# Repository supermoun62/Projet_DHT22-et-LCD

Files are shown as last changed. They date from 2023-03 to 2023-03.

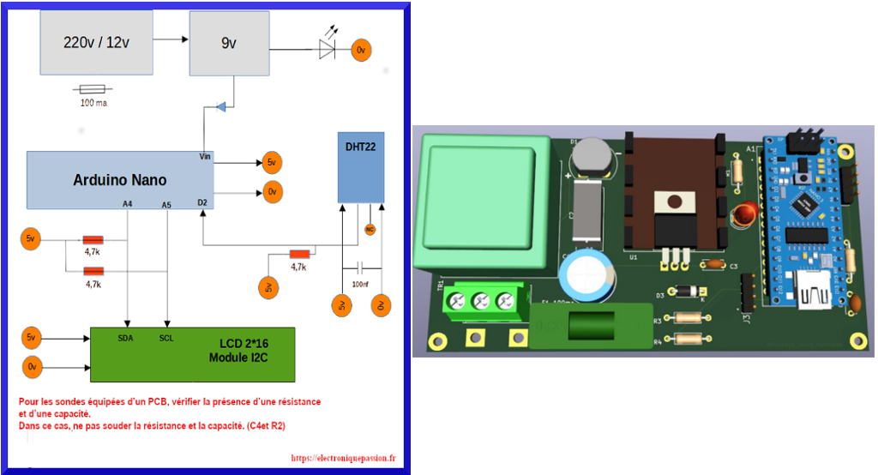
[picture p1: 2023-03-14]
Image_Synoptique_et_PCB_Affichage_DHT22.png

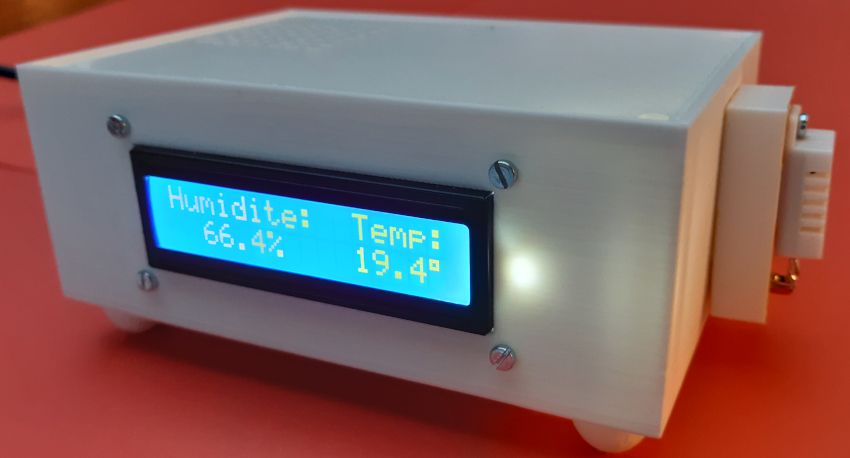
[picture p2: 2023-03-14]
Image_Coffret_Fini_V2.png

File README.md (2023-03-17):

# Projet_DHT22-et-LCD
Programme pour afficher H et T directement de la sonde: Affichage_DHT22_H_et_T.ino

Programme pour afficher H et T sur le LCD: Programme pour afficher H et T.ino.

Librairies: Adafruit_Sensor-master.zip  DHT-sensor-library-master.zip  LiquidCrystalI2C112.zip

Calibration_Affichage_DHT22: DHT22_Calibration_Temperature.pdf

Documentations techniques

Image 3D du PCB: DHT22_Calibration_Temperature.jpg.

Liste du materiel:  Liste_Materiel_Affichage_Temp_Humidite.pdf.

PCB Gerber.

PCB Pdf.

Schema: Affichage_Temp_Humidite.pdf.

Fichiers STL.

Le detail du projet:  Arduino_Affichage_DHT22.pdf.

https://github.com/supermoun62/Projet_DHT22-et-LCD/blob/main/Image_Coffret_Fini_V2.png

https://github.com/supermoun62/Projet_DHT22-et-LCD/blob/main/Image_Synoptique_et_PCB_Affichage_DHT22.png

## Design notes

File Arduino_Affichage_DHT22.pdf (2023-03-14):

## Arduino – Affichage température et Humidité avec un DHT22

Affichage température et Humidité avec un DHT22 | http://electroniquepassion.fr

### 1 Sur 10

# PROJET

Afficher la température et l’humidité avec in DHT22 et un écran LCD 12*16 avec un bus I2C

220v / 12v | 9v

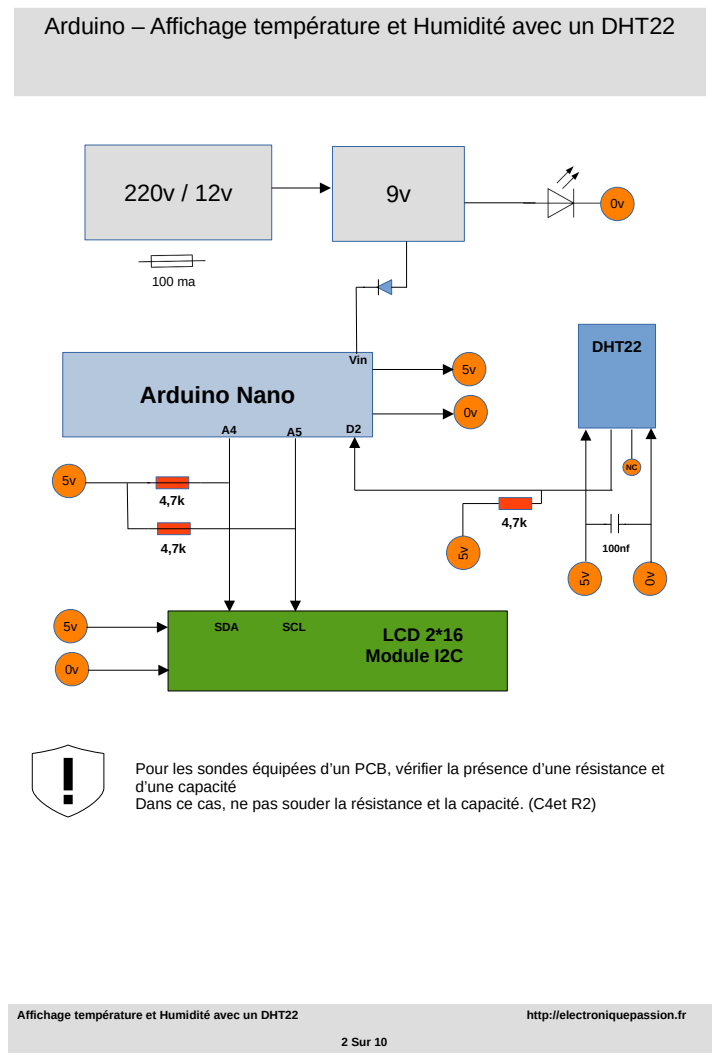
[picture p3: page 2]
2 Sur 10; Arduino Nano; LCD 2*16 Module I2C; SDA; SCL; DHT22; Vin

Pour les sondes équipées d’un PCB, vérifier la présence d’une résistance et
d’une capacité
Dans ce cas, ne pas souder la résistance et la capacité. (C4et R2)

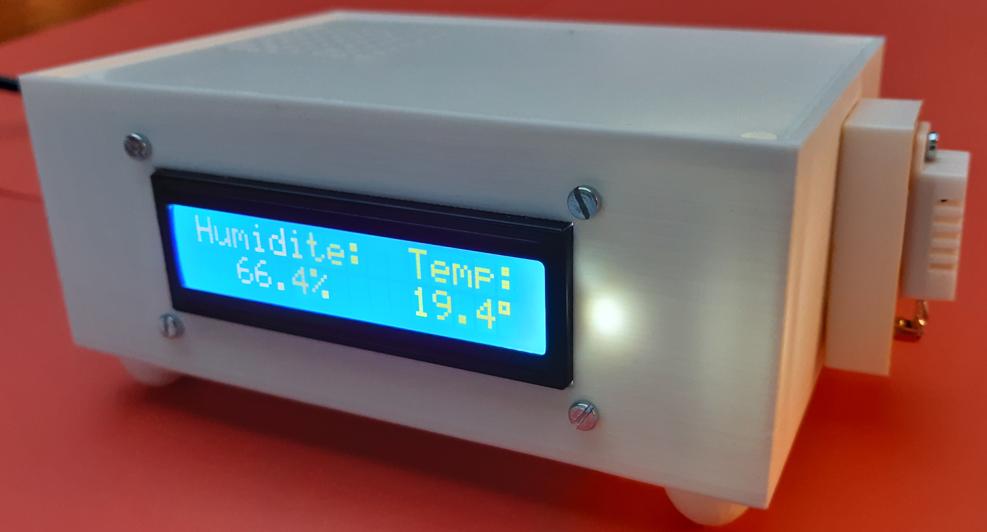
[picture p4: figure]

### 3 Sur 10

Matériel utilisé:

Arduino Nano

LCD 2*16 Bus I2C
DHT22

Librairies:
Wire.h
LiquidCrystal_I2C (https://github.com/sui77/rc-switch) | ICI (https://github.com/fdebrabander/Arduino-LiquidCrystal-I2C-library) ou par le gestionnaire de librairies ou (https://github.com/sui77/rc-switch) ICI (https://www.gotronic.fr/pj2-sbc-lcd16x2-fr-1441.pdf) DHT-sensor-library de Adafruit (https://github.com/sui77/rc-switch)

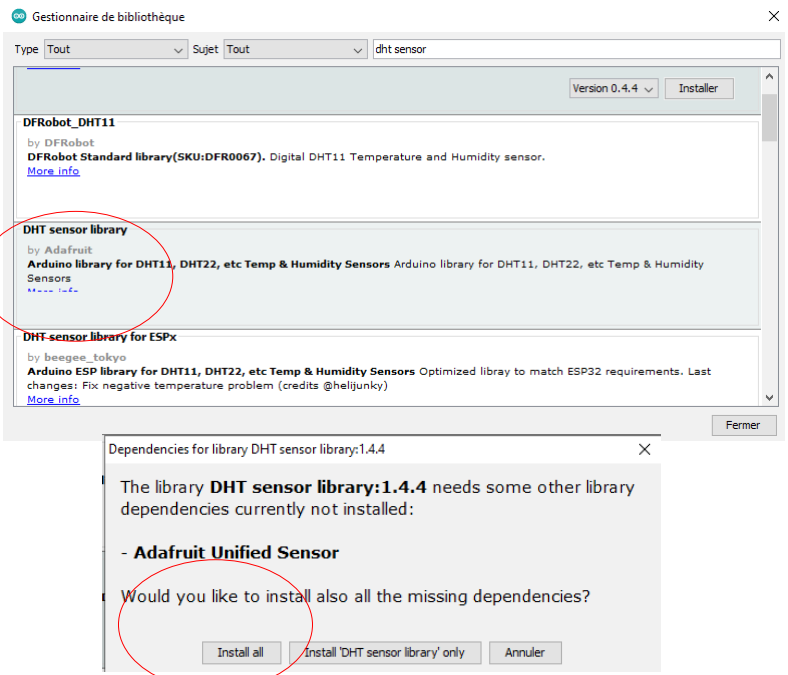
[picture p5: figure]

### 4 Sur 10

### 5 Sur 10

| DHT11 | DHT22 (2302)
U | 3 à 5,5v | 3,3 à 6v
Plage de mesures | 0°c à 50°c | -40°c à 80°c
Précision température | ± 2°c | ±- 0,5°c
Résolution température | 1°c | 0,1°c
Plage de mesures humidités | 20 % à 80 % | 0 % à 100 %
Précision humidité | ± 5 % | ± 2 à 5 %
Résolution humidité | 1 % | 0,1 %
Courant max | 2,5ma | 1,5ma
Courant au repos | 150µa | 50µa
Fréquence collecte mesures | 1 par seconde | 2 par seconde

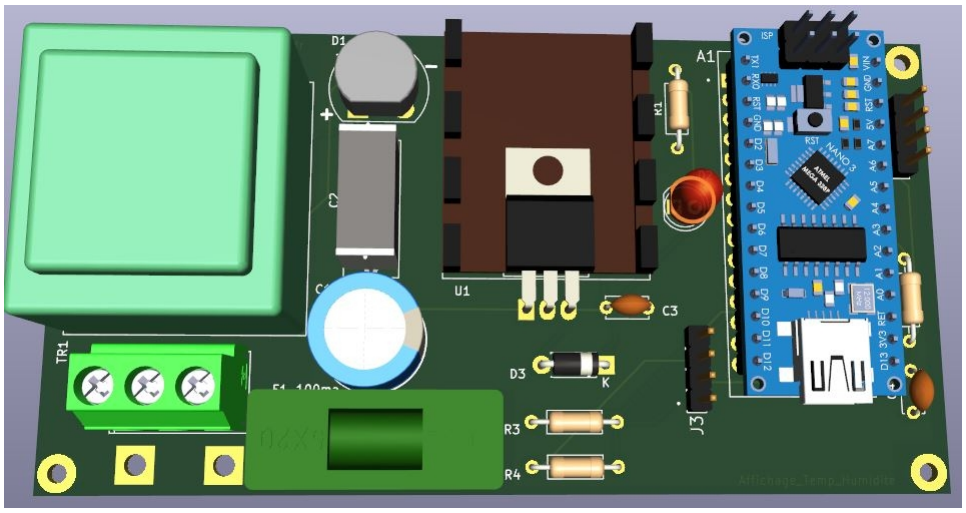
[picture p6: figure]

### 6 Sur 10

## PCB embase 15br

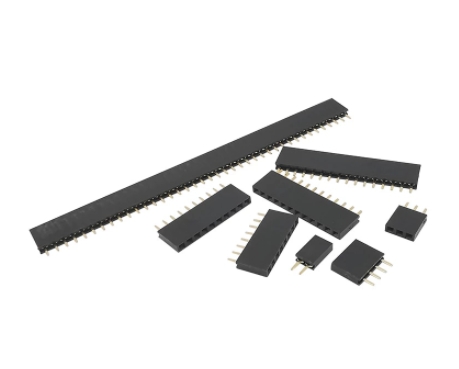
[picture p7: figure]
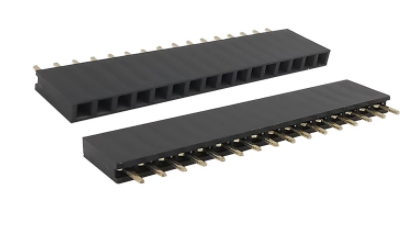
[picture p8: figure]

### 7 Sur 10

ICI (https://fr.aliexpress.com/item/4000852908837.html?spm=a2g0s.9042311.0.0.41a46c372WkNYm)

### 8 Sur 10

DHT | T Réelle | Corrigé
17,5 | 16 | 15,96
18,6 | 17 | 17,02
19,7 | 18 | 18,08
20,6 | 19 | 18,94
0 | 5 | 10 | 15 | 20 | 25

0

5

10

15

20

f(x) = 0,9594 Val_T − 0,8247 R² = 0,9978

Courbe de tendance avec couvercle

DHT22 valeur T

T

Réelle

J’ai repris le tuto de Steph Ubaud: https://www.youtube.com/watch?v=lJU6JCm94O8

Ou Tutoriel Calc - nuage de points et courbe d'ajustement (https://scolawebtv.crdp-versailles.fr/?id=36132) de Vincent Schoeffter

Pour les relevés de mesure , utiliser le fichier : Affichage_DHT22_H_et_T.ino

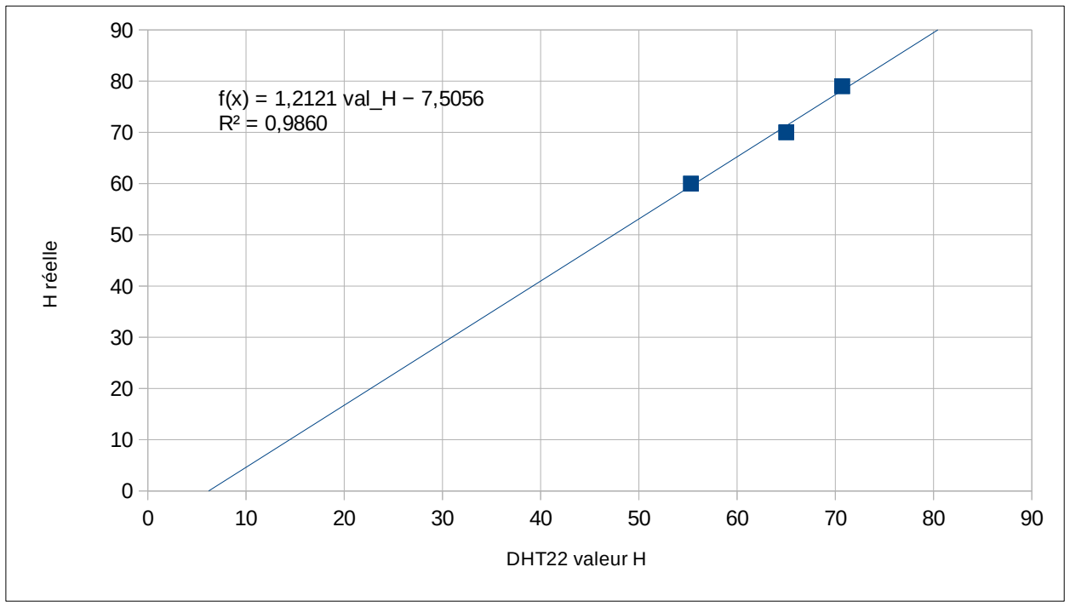
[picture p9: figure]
f(x) = 1,2121 val_H − 7,5056 R² = 0,9860; DHT22 valeur H; H réelle

### 9 Sur 10

DHT | H Réelle | Corrigée
49,6 | 54 | 52,61
55,3 | 60 | 59,52
65 | 70 | 71,28
70,7 | 79 | 78,19

### 10 Sur 10

1:
Pour les essais, utiliser le fichier Affichage_DHT22_H_et_T.ino Coffret fermé afin de relever les valeurs de H et T fournies parle DHT22.

2:
Après les relevés, faire les courbes de tendance afin de calibrer la sonde.

3:
Corriger les valeurs dans le fichier Affichage_DHT22_V6.ino

4:
Téléverser le programme Affichage_DHT22_V6.ino.

Ruban adhésif thermique
Cpix.fr réf : D00827-V3

## COFFRET

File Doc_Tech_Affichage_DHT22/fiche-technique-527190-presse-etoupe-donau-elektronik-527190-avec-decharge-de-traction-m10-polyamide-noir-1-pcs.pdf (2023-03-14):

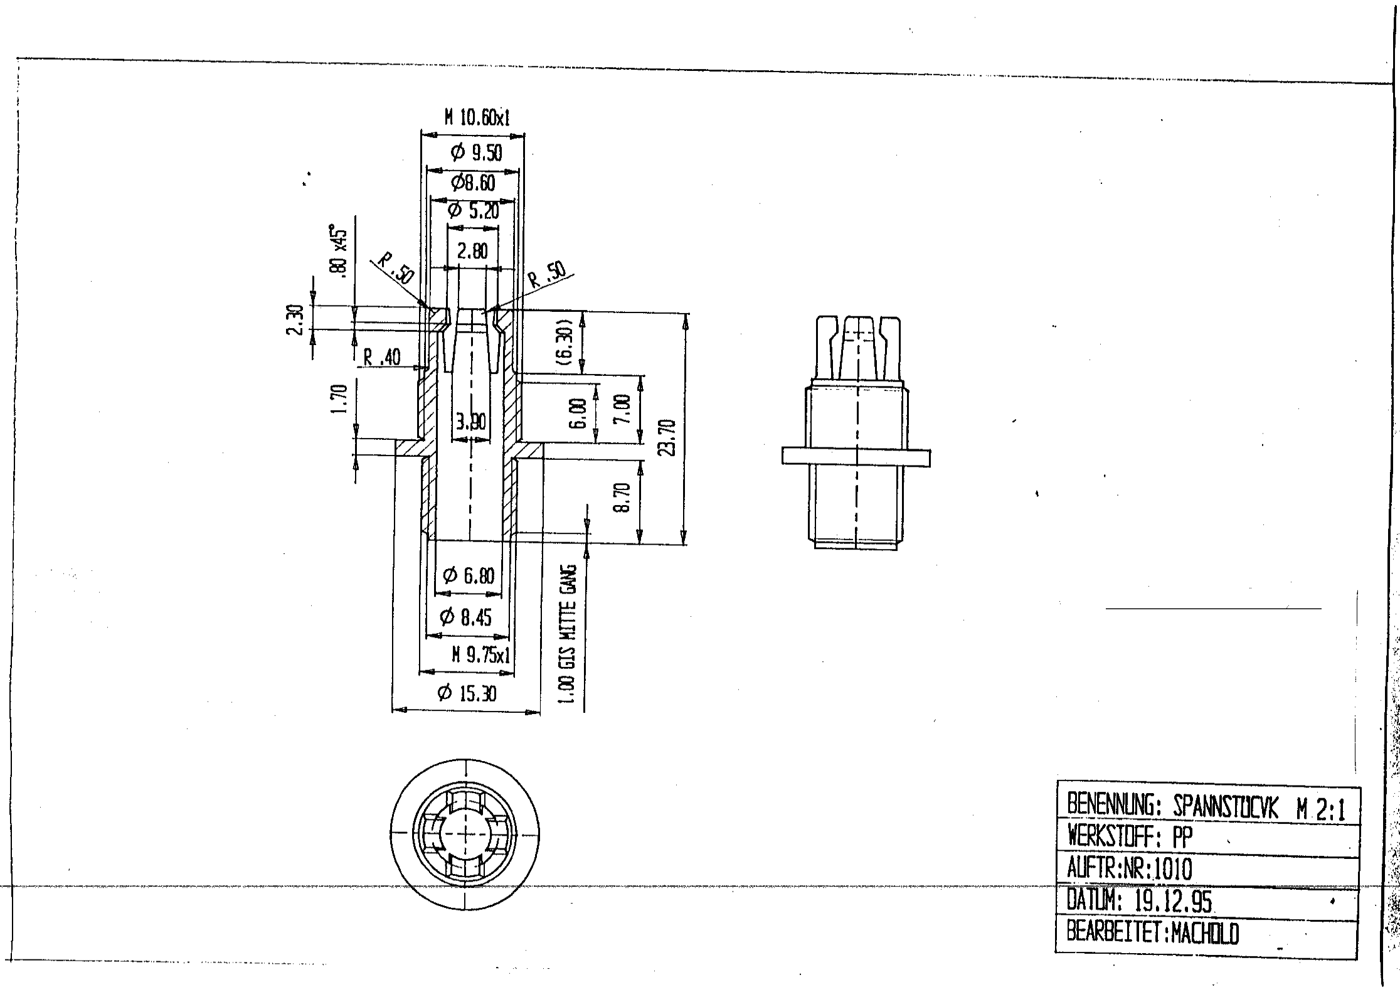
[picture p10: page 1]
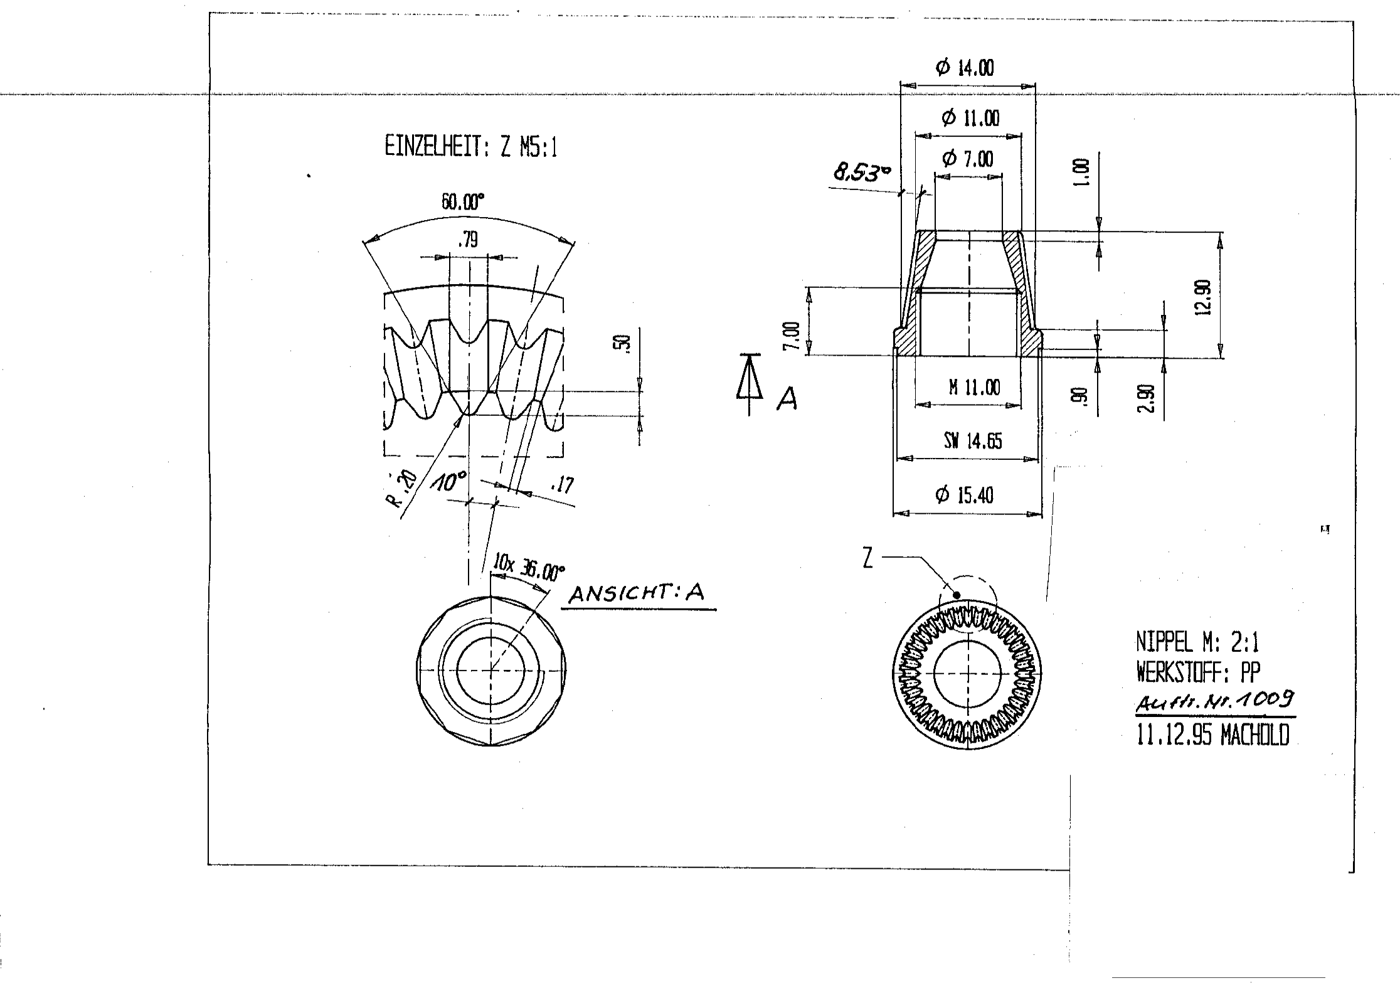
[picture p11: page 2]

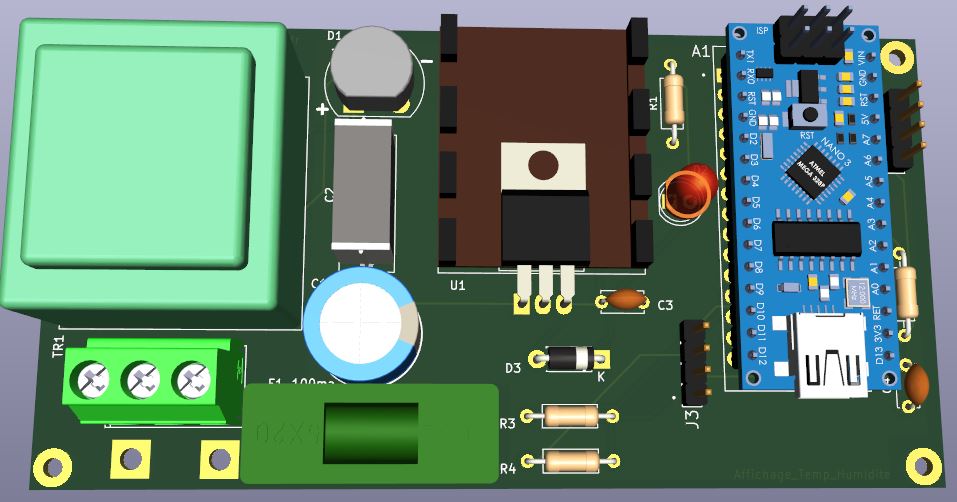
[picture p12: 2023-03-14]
Image_3D_Affichage_DHT22/Image-3D_V2_Affichage_Temp_Humidite.JPG

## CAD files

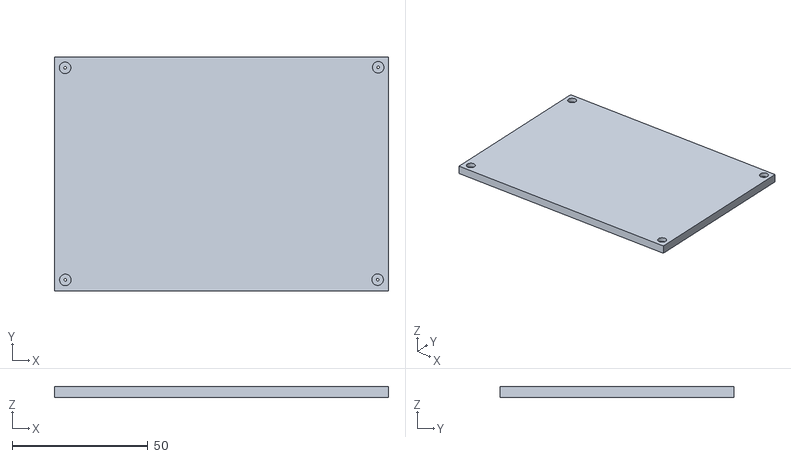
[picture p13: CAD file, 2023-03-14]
STL_Affichage_DHT22/Couvercle_Coffret_Affichage_DHT22_V2.stl
123.0 x 86.0 x 4.00

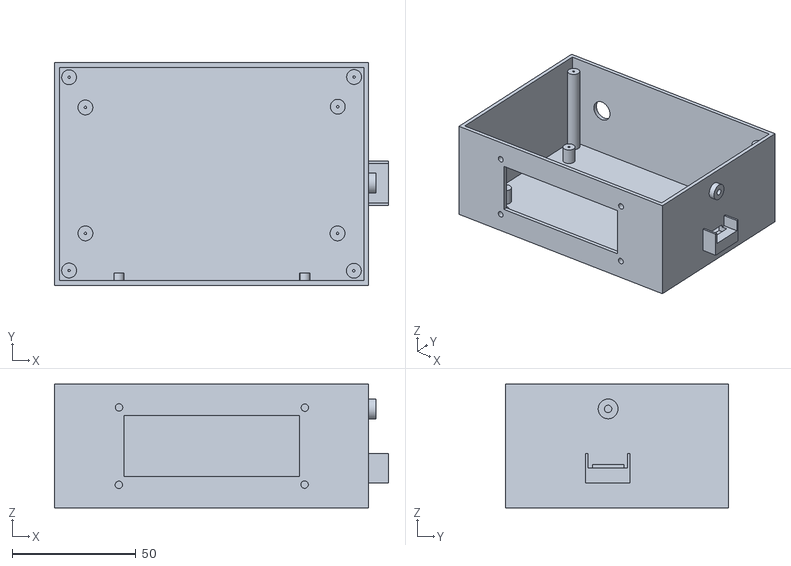
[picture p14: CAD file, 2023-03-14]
STL_Affichage_DHT22/Coffret_Affichage_DHT22_V3.stl
135.0 x 90.0 x 50.0

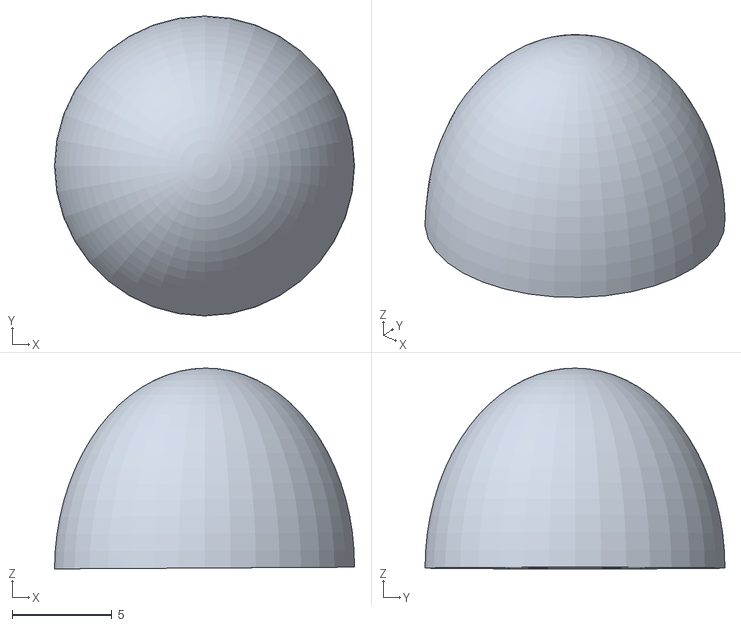
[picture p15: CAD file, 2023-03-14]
STL_Affichage_DHT22/Support_coffret_Affichage_DHT22.stl
15.0 x 15.0 x 10.0

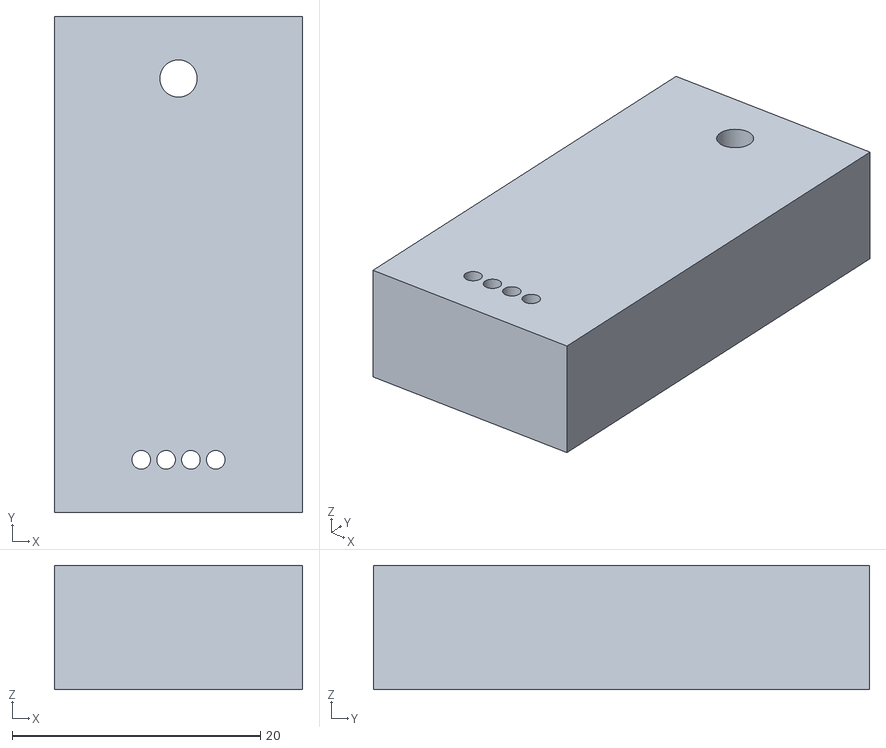
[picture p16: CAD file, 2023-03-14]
STL_Affichage_DHT22/Modification-DHT22.stl
20.0 x 40.0 x 10.0

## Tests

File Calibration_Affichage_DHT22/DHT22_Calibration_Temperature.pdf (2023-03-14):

DHT22_Calibration_Temperature, Page 1

DHT | T Réelle | Corrigée
17,5 | 16 | 15,96
18,6 | 17 | 17,02
19,7 | 18 | 18,08
20,6 | 19 | 18,94
0 | 5 | 10 | 15 | 20 | 25

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
f(x) = 0,9594 Val_T − 0,8247 R² = 0,9978

## Courbe de tendance avec couvercle

DHT22 valeur T

T

Réelle

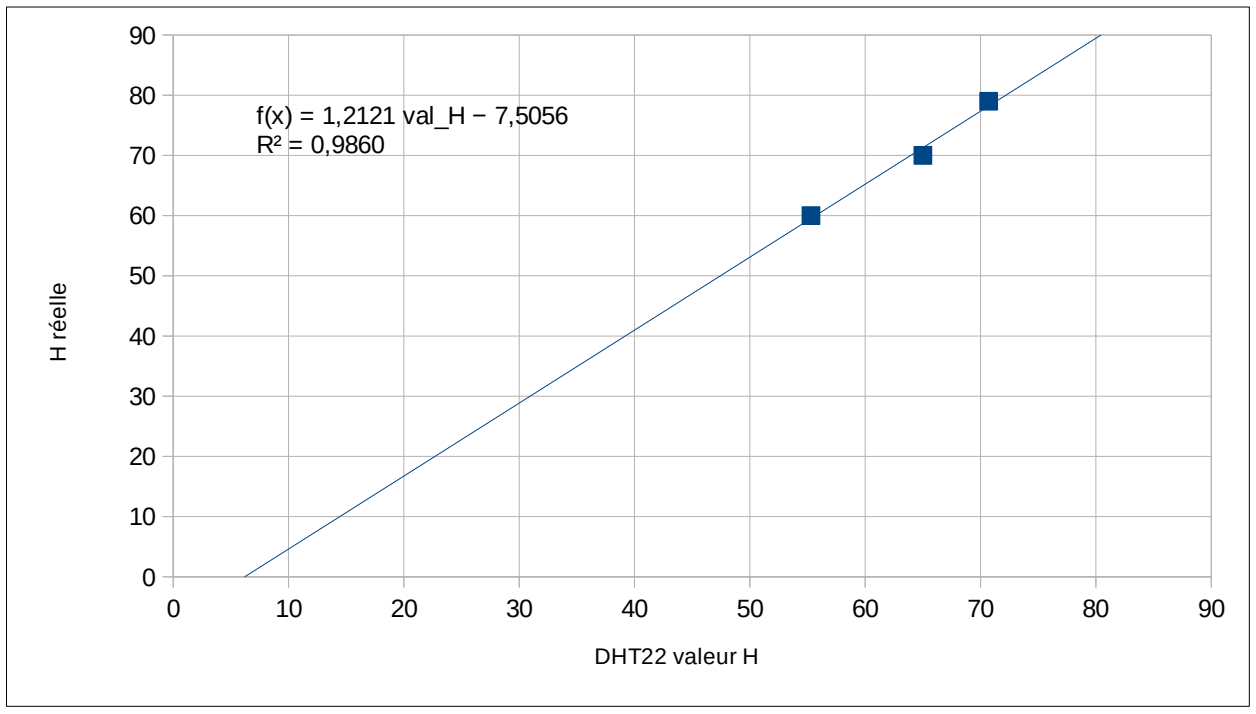
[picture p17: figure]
f(x) = 1,2121 val_H − 7,5056 R² = 0,9860; DHT22 valeur H; H réelle

DHT22_Calibration_Temperature, Page 2

DHT | H Réelle | Corrigée
49,6 | 54 | 52,61
55,3 | 60 | 59,52
65 | 70 | 71,28
70,7 | 79 | 78,19

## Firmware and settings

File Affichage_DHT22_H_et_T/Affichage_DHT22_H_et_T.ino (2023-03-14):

/*
 Description: Programme permettant d'afficher sur un afficheur liquid-crystal, température et taux d'humidité
              mesurés par un DHT22, branché sur la pin D2.

 Auteur:  Christian Mercier  
 Créé le:  

 Librairies utilisées: DHT sensor library https://github.com/adafruit/DHT-sensor-library
                                          https://github.com/adafruit/DHT-sensor-library                                        
                     : Liquid-crystal-I2C https://www.arduinolibraries.info/libraries/liquid-crystal-i2-c                                                                 
                     : Wire 
                     
 Informations sites:    https://www.volta.ma/comment-utiliser-les-capteurs-dht11-et-dht22-avec-arduino/arduino/
                        https://scolawebtv.crdp-versailles.fr/?id=36132  
                        https://www.youtube.com/watch?v=lJU6JCm94O8                                           
  */
#include <Wire.h>
#include <LiquidCrystal_I2C.h>
LiquidCrystal_I2C lcd(0x27,16,2);// Adresse,lignes,colonnes

#include <Adafruit_Sensor.h>
#include <DHT.h>
#include <DHT_U.h>

#define DHTPIN 2 // Pin raccordement DHT22
//#define DHTTYPE DHT11 // DHT 11
#define DHTTYPE DHT22 // DHT 22  (AM2302), AM2321
//#define DHTTYPE DHT21 // DHT 21 (AM2301)
DHT dht(DHTPIN, DHTTYPE); // Instance librairie DHT
  float valeurH = 0.0;
  float valeurT = 0.0;
  float valeurTcorrigee = 0.0;
  float valeurTressentie = 0.0;
  float valeurRessentieEnCelsius = 0.0;
  float var1T = 0.9594; // En fonction de la courbe de tendance
  float var2T = 0.8247; // En fonction de la courbe de tendance

  byte bitDefaut1;
  byte bitDefaut2;
  const int pinLed13 = 13;
//---------------------------------------
void setup ()
{     
  Serial.begin(9600);     
  dht.begin(); // Init DHT22;
  
  lcd.init();// init Afficheur                    
  lcd.backlight();// Active retro-eclairage
  lcd.setCursor(1,0);// Colonne, Ligne
  lcd.print(" Capteur DHT22");
      
  pinMode(pinLed13, OUTPUT);
  digitalWrite(pinLed13, LOW);     

  bitDefaut1 = LOW; 
  bitDefaut2 = LOW;
  
  delay(1000);  
  lcd.clear();// Effacement LCD     
}// fin Setup 
//--------------------------------------------
void loop ()
{
// Appel routine releves temp et humidité du DHT22
  InfosTempEtHumidite(); 
}// Fin LOOP
//--------------------------------------------
void InfosTempEtHumidite()
{  
  float H = dht.readHumidity(); // Humidité en %
  delay(100);
  float T = dht.readTemperature();
  delay(100);
  valeurRessentieEnCelsius = dht.computeHeatIndex(T, H, false); // False = °C
  valeurH = H;
  valeurT = T;
  valeurTressentie = valeurRessentieEnCelsius;
// Calcul T avec courbe de tendance
  valeurTcorrigee = (float)var1T*valeurT-var2T;     
if (isnan(H) || isnan(T))
  {  
    bitDefaut1 = HIGH;
    digitalWrite(pinLed13, HIGH); 
      if (bitDefaut2 == LOW)
        {
          Affichage_defaut_LCD();  
        }
    return;      
  }
else
  {
    bitDefaut1 = LOW;      
      
      if(bitDefaut1 == LOW & bitDefaut2 == HIGH)
        {
          lcd.clear();     
        }    
    bitDefaut2 = LOW;
    digitalWrite(pinLed13, LOW);    
// Appel Routine Affichage H  
    Affichage_H_LCD();
    delay(100);    
// Appel Routine Affichage Tcorrigee    
    Affichage_T_LCD();     
  }    
  Serial.print(valeurT); Serial.print("---");Serial.print(valeurTcorrigee); 
  Serial.println();
  delay(2000); 
}// FIN VOID
//--------------------------------------------
void Affichage_H_LCD()
{
  lcd.setCursor(0,0);// colonne, ligne
  lcd.print("Humidite:");
  lcd.setCursor(11,0);
  lcd.print(valeurH);
  lcd.setCursor(6,1);
  lcd.print("%");    
}// FIN VOID 
//--------------------------------------------
void Affichage_T_LCD()
{
  lcd.setCursor(0,1);// // colonne, ligne 
  lcd.print("Temp:");  
  lcd.setCursor(11,1);  
  lcd.print(valeurT);  
  lcd.setCursor(15,1);
  lcd.print((char)223); //caractere degre    
}// FIN VOID
//--------------------------------------------
void Affichage_defaut_LCD()
{ 
  lcd.clear();
  lcd.setCursor(1,0);// // colonne, ligne
  lcd.print("Defaut capteur");
  lcd.setCursor(0,1);
  lcd.print("----------------");
  bitDefaut2 = HIGH;       
}// FIN VOID 

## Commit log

2023-03-14 Projet DHT et LCD C. Mercier 14/03/2023
    [Affichage_Temp_Humidite-B_Adhesive.gbr, Affichage_Temp_Humidite-B_Courtyard.gbr, Affichage_Temp_Humidite-B_Cu.gbr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]
2023-03-17 Modification fichier Arduino_Affichage_DHT22.pdf C. Mercier 17/03/2023
